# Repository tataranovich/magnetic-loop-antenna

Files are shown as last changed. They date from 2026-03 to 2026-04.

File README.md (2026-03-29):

# Magnetic Loop Antenna

Magnetic loop antenna for receiving HAM radio bands with the following features:

- control over WiFi from web browser
- automatic antenna tune on frequency change in `rtl_tcp` source

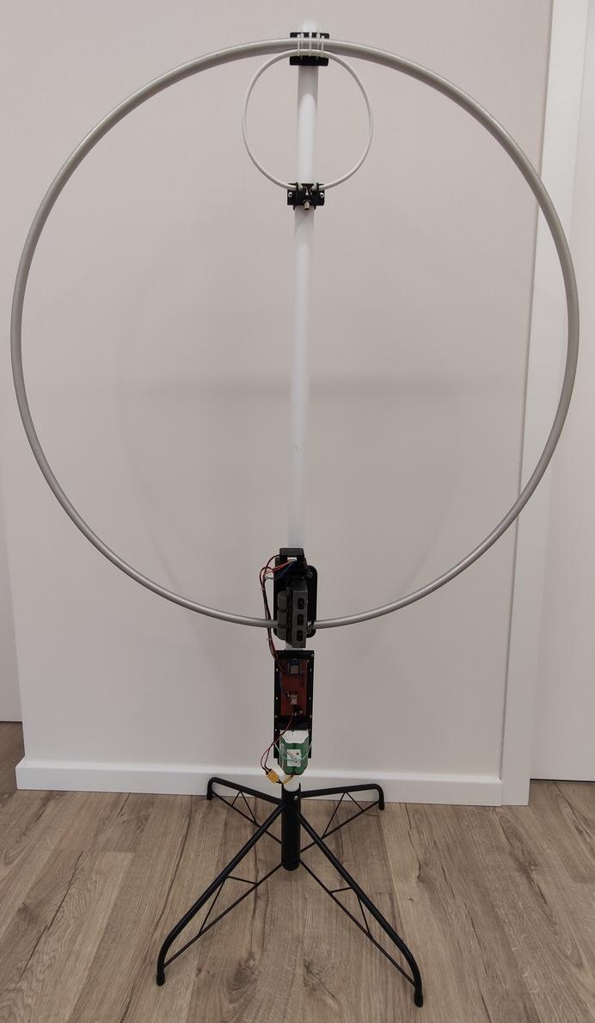
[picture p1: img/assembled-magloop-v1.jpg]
Assembled antenna


Designed using FreeCAD, STL files for printing can be found in `stl` directory.

Assembly details are written in Russian in [blog post](https://blog.tataranovich.com/2026/03/magnetic-loop-antenna.html). Use Google translate if needed.

## Automated Tune

Simple python script to adjust antenna controller settings to match frequency change in `rtl_tcp` backend.

```bash
sudo apt-get update
sudo apt-get install -y rtl-sdr

sudo mkdir /opt/magloop
sudo useradd -r -d /opt/magloop -s /usr/sbin/nologin -G plugdev magloop
sudo install -o root -m 644 magloop-tuner.py /opt/magloop/
sudo install -o root -m 644 magloop-tuner.service /etc/systemd/system/
sudo systemctl daemon-reload
sudo systemctl enable --now magloop-tuner.service
```

## Manual Tune

Antenna can be manually managed from web browser over Wifi or by push buttons at controller board.

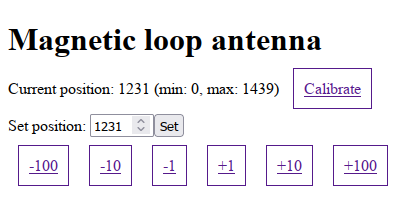
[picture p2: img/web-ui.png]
Web UI


- execute position calibration routine
- set absolute position
- set increase/decrease relative position with different increments

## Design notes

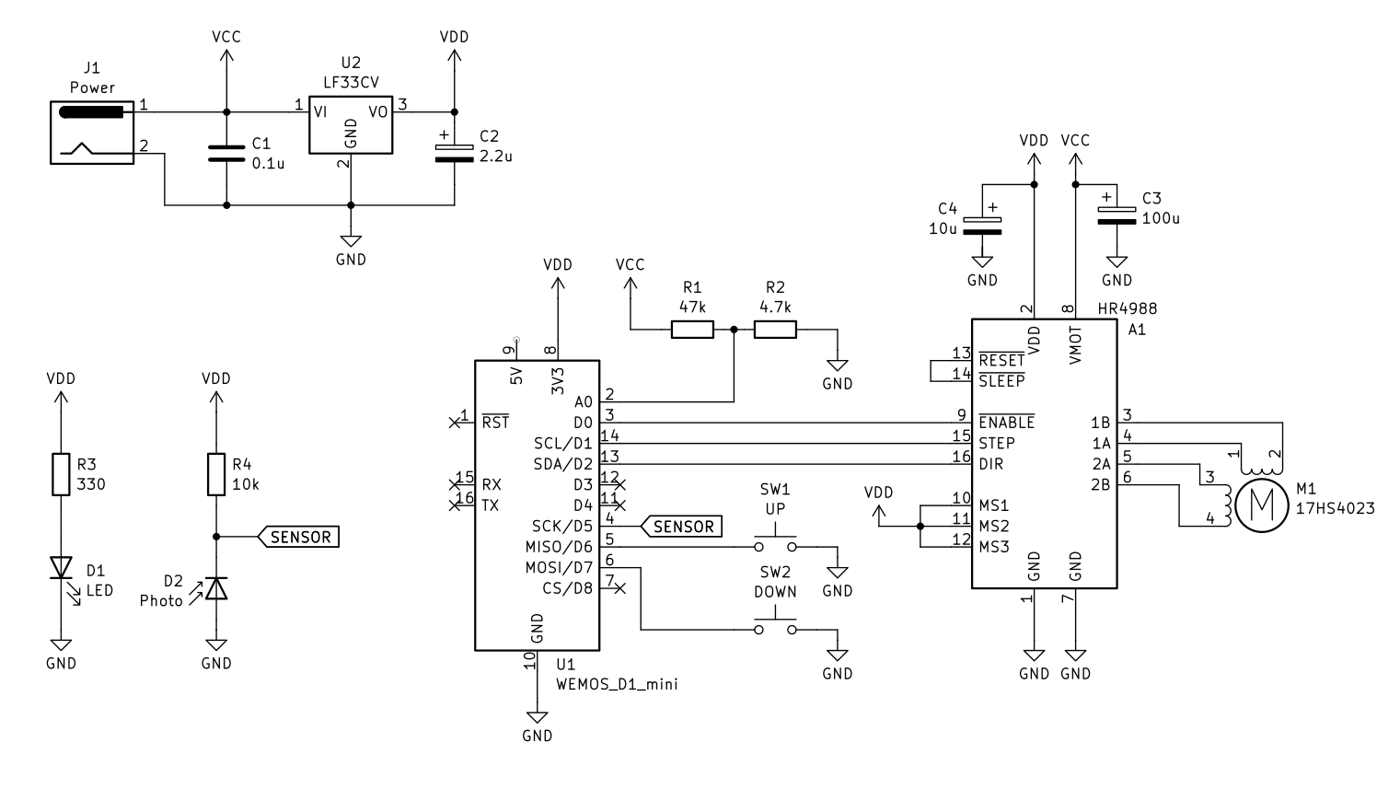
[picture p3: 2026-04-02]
img/magloop-controller-schematic.png

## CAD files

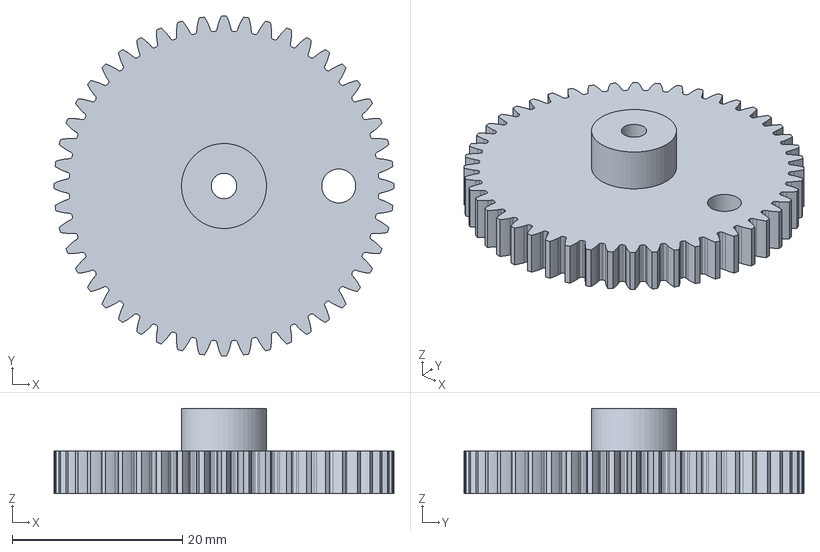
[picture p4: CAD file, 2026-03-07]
freecad/main-geer.FCStd
40.0 x 40.0 x 10.0 mm

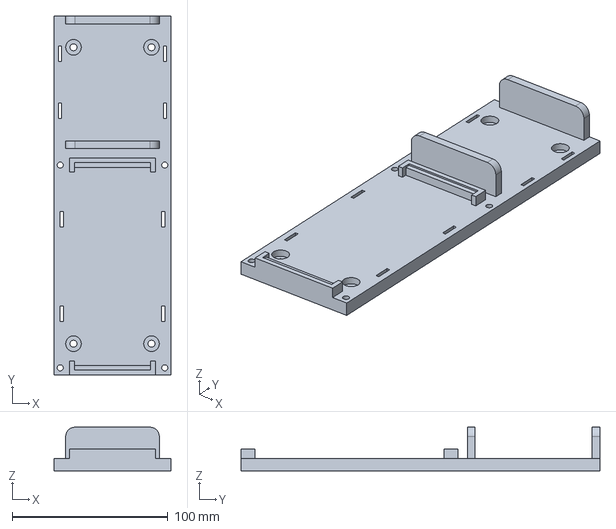
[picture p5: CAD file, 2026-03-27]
freecad/breadboard-stand.FCStd
75.0 x 230.0 x 28.0 mm

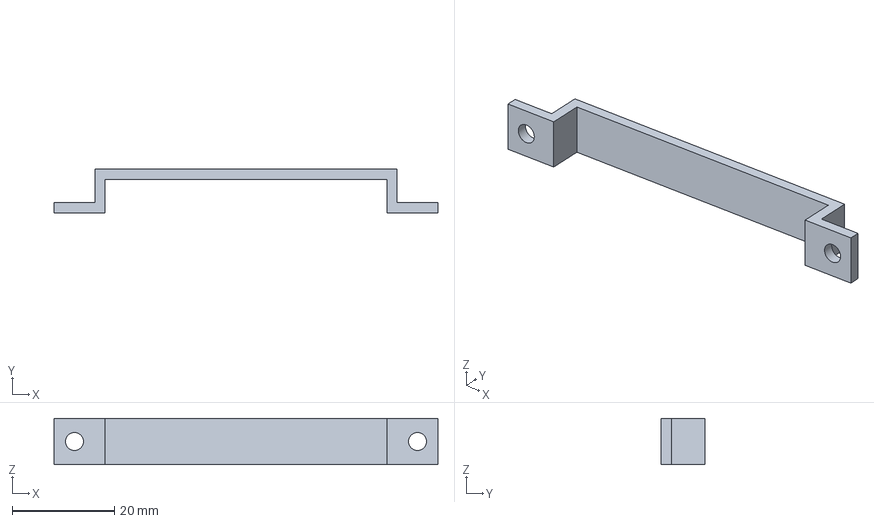
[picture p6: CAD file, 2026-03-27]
freecad/breadboard-skoba.FCStd
75.0 x 8.50 x 9.00 mm

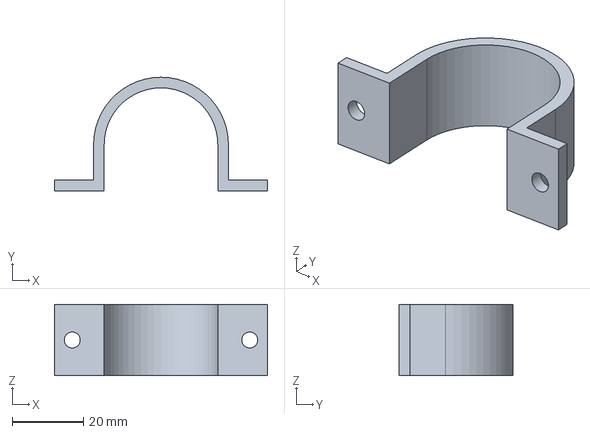
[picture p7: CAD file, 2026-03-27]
freecad/skoba.FCStd
60.0 x 32.0 x 20.0 mm

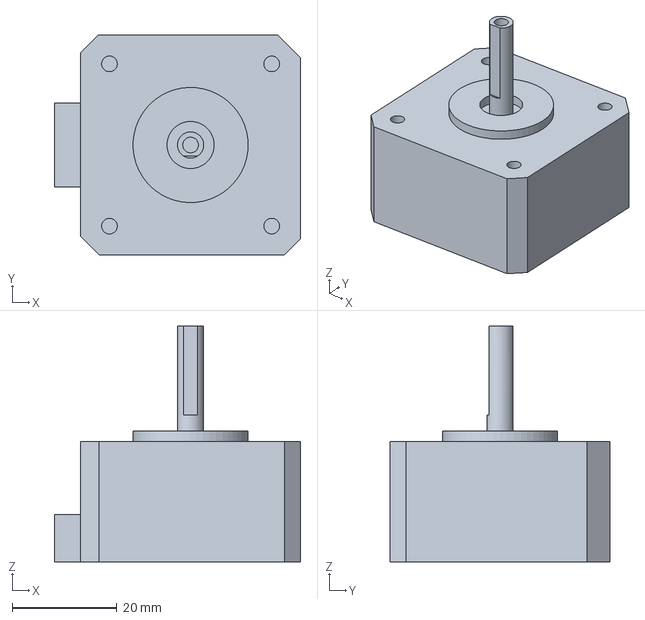
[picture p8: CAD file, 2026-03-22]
freecad/stepper.FCStd
47.0 x 42.0 x 45.0 mm

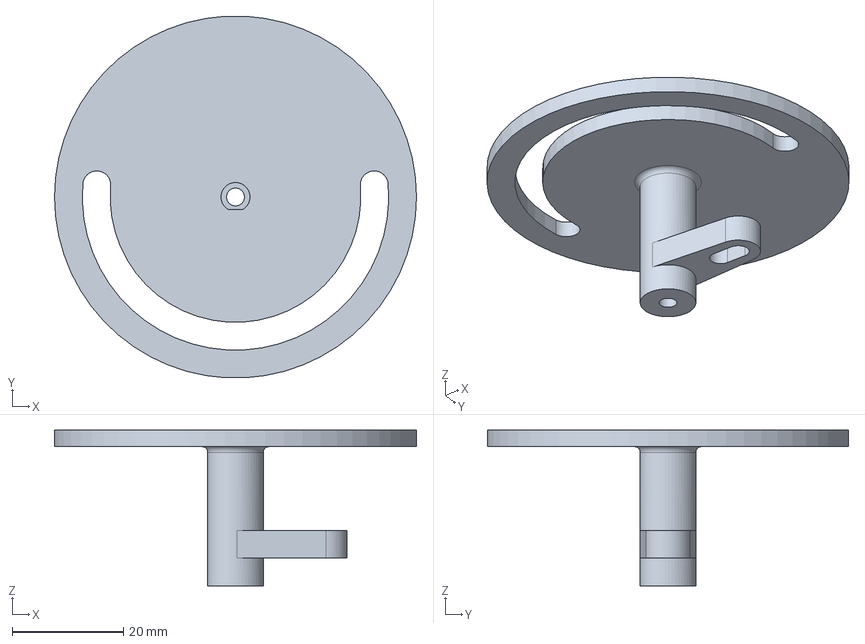
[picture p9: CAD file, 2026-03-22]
freecad/stepper-shaft.FCStd
65.0 x 64.9 x 28.0 mm

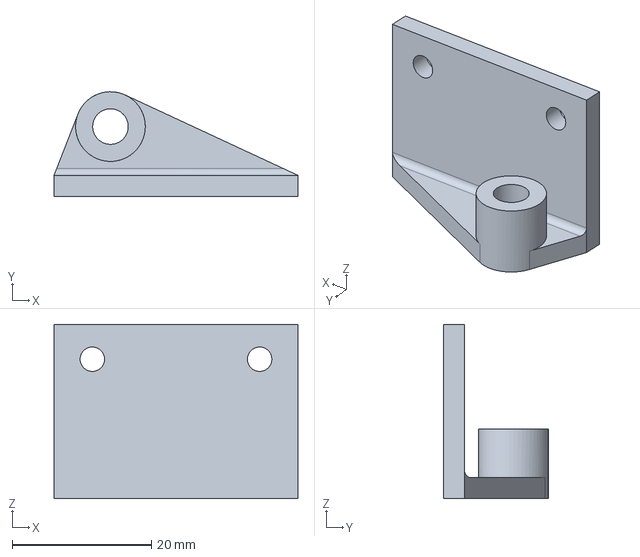
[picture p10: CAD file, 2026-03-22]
freecad/led-stand.FCStd
35.0 x 15.0 x 25.0 mm

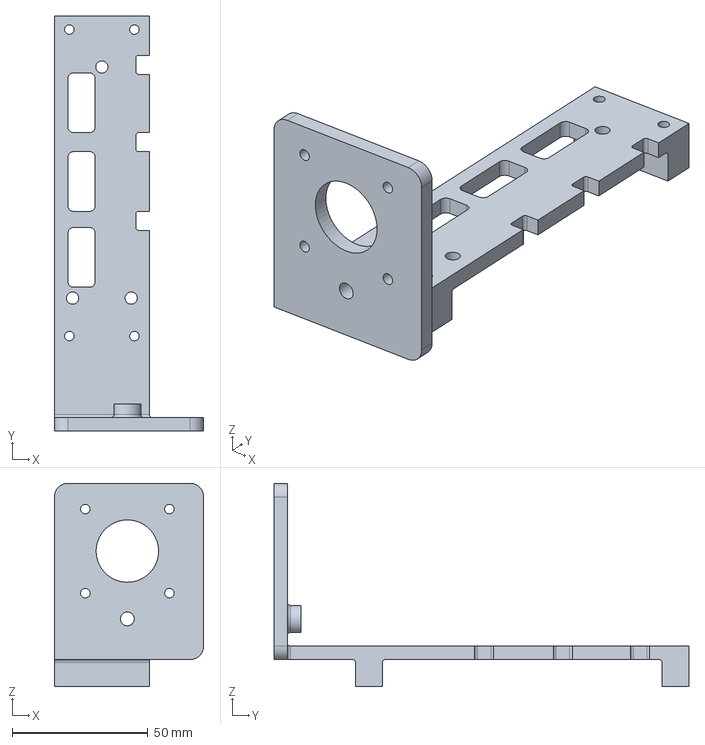
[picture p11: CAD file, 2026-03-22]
freecad/body.FCStd
55.0 x 153.0 x 75.0 mm

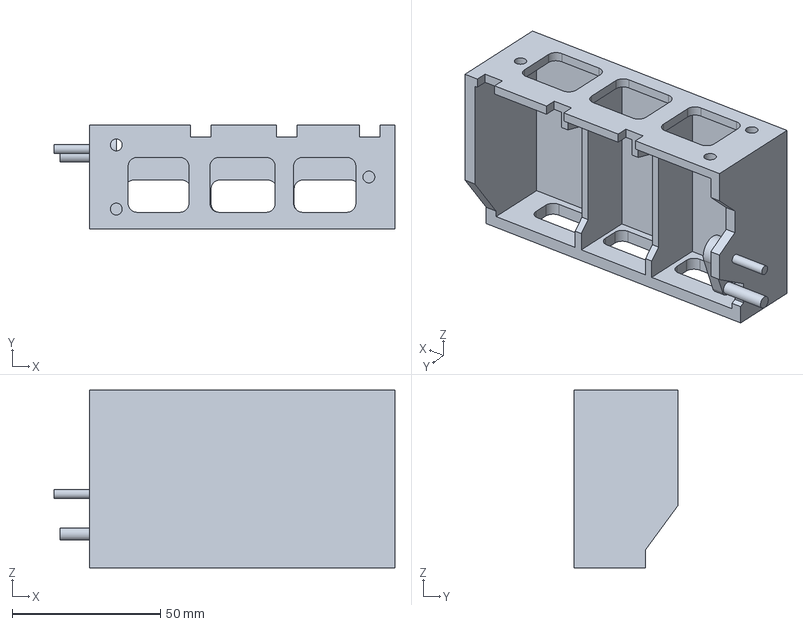
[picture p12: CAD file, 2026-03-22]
freecad/kpe.FCStd
115.0 x 35.0 x 60.0 mm

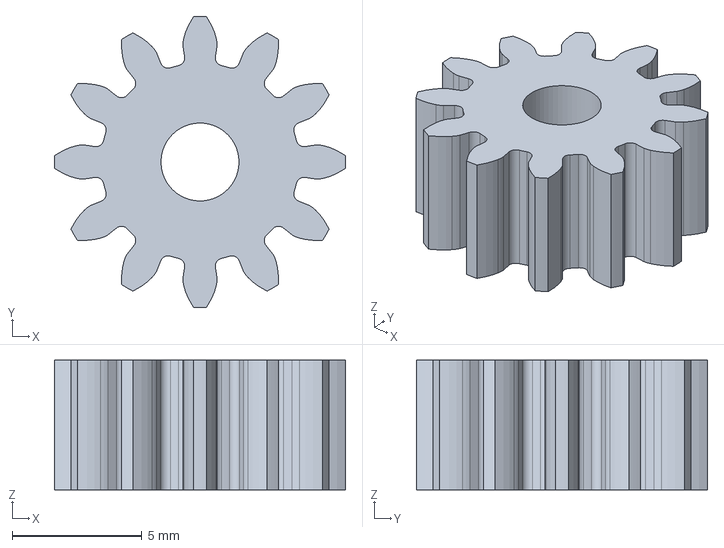
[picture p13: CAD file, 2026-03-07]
freecad/vernier-geer.FCStd
11.2 x 11.2 x 5.00 mm

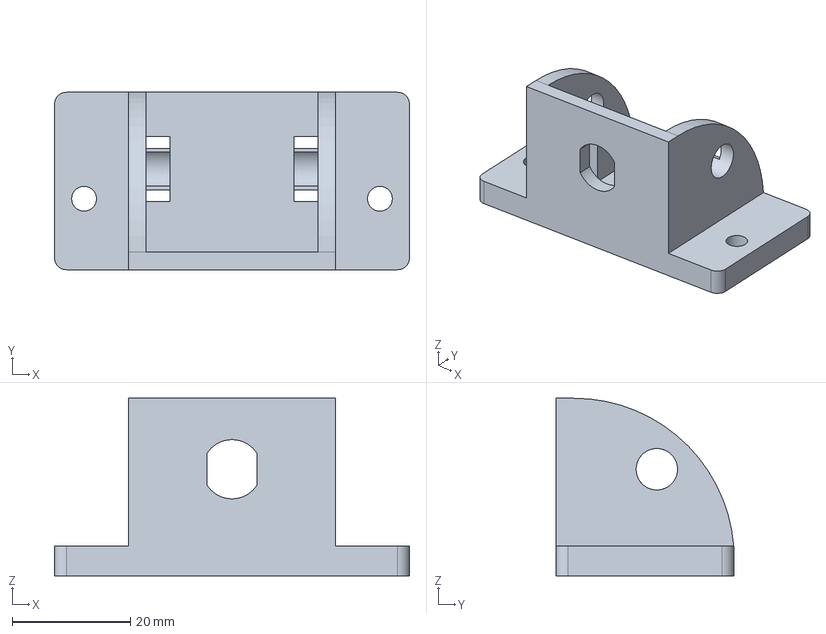
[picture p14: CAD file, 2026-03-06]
freecad/bnc-plate2.FCStd
60.0 x 30.0 x 30.0 mm

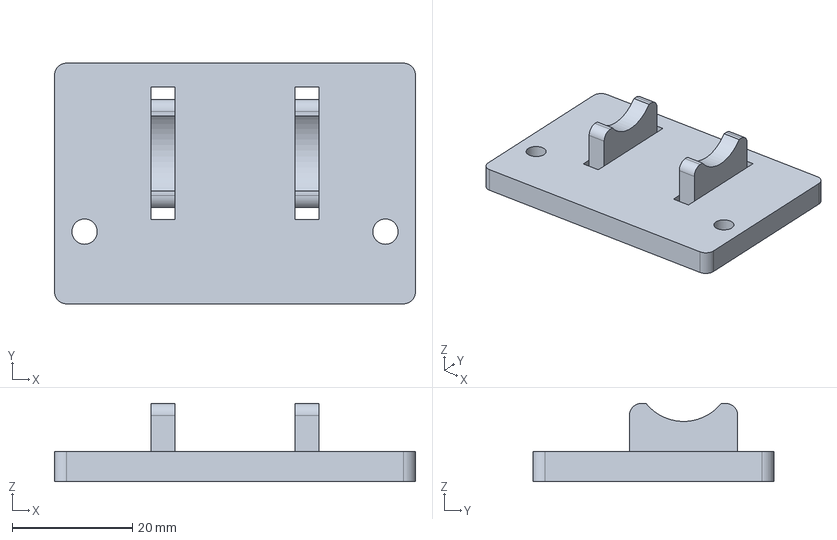
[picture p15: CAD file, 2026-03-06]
freecad/loop-plate.FCStd
60.0 x 40.0 x 13.0 mm

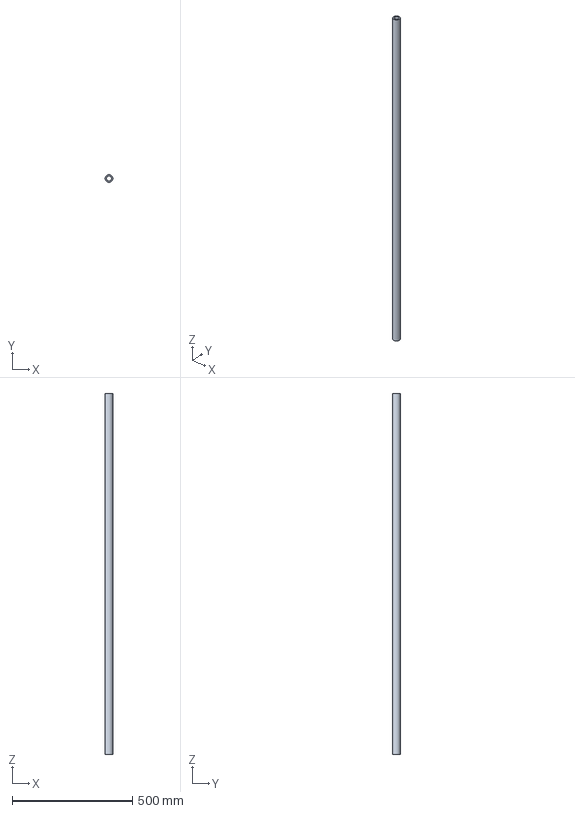
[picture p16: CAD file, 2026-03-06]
freecad/shtanga.FCStd
32.0 x 32.0 x 1500.0 mm

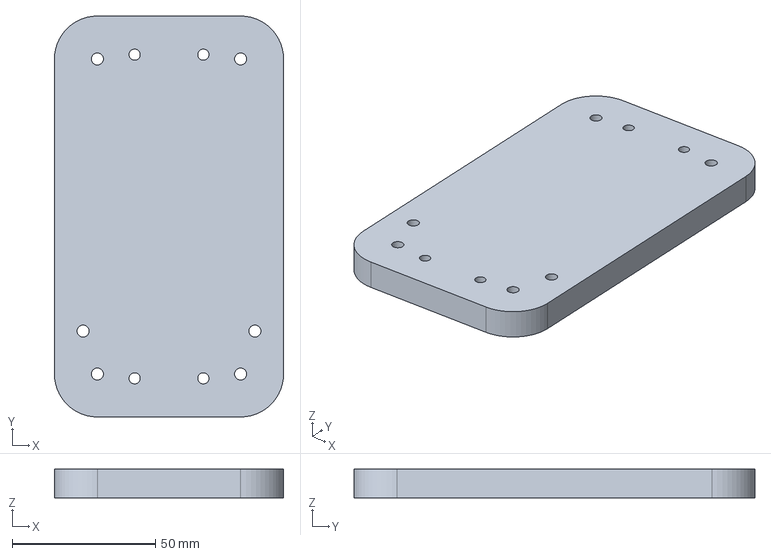
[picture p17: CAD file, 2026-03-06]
freecad/plate.FCStd
80.0 x 140.0 x 10.0 mm

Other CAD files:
freecad/breadboard-assembly.FCStd
freecad/stepper-assembly.FCStd
freecad/Assembly.FCStd
freecad/circle.FCStd
freecad/circle2.FCStd
freecad/end.FCStd
stl/bnc-plate2.stl
stl/body.stl
stl/breadboard-skoba.stl
stl/breadboard-stand.stl
stl/end.stl
stl/led-stand.stl
stl/loop-plate.stl
stl/main-geer.stl
stl/plate.stl
stl/skoba.stl
stl/stepper-shaft.stl

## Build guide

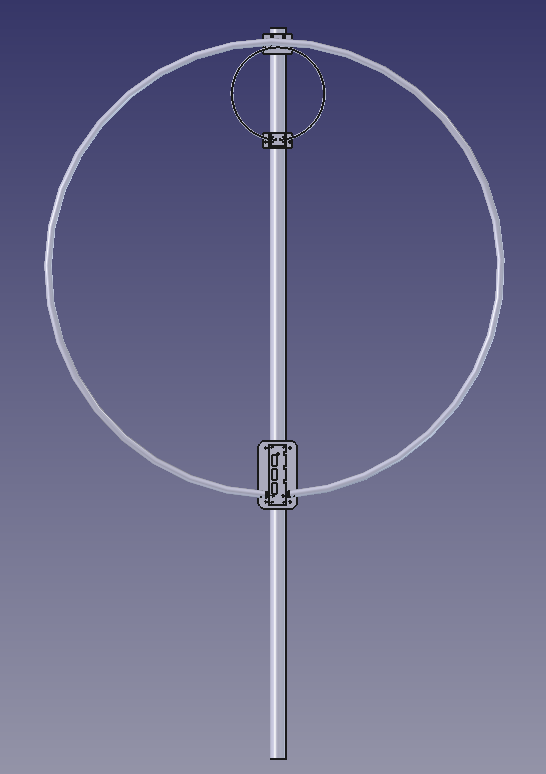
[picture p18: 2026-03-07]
img/magloop-assembly.png

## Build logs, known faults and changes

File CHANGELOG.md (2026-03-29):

# Changelog

All notable changes to this project will be documented in this file.

The format is based on [Keep a Changelog](https://keepachangelog.com/en/1.1.0/),
and this project adheres to [Semantic Versioning](https://semver.org/spec/v2.0.0.html).

## [Unreleased]

### Added

- FreeCAD models for virtual assembly.
- STL files for 3D printing.
- Manual tuning from web browser over WiFi.
- Automatic tuning for `rtl_tcp` backend.

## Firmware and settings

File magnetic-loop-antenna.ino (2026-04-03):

#include "config.h"

#include <ESP8266WiFi.h>
#include <ESP8266WebServer.h>

#define ENABLE_PIN D0
#define STEP_PIN D1
#define DIR_PIN D2
#define SENSOR_PIN D5
#define BTN_UP_PIN D6
#define BTN_DOWN_PIN D7

#define DIR_UP HIGH
#define DIR_DOWN LOW

#define SENSOR_NORMAL LOW
#define SENSOR_ALERT HIGH

#define POSITION_MARGIN 150

#define VOLTAGE_MAX 35.0 // 47k + 4.7k resistor divider
#define VOLTAGE_MIN 12.0 // Stop WiFi and go to infitinite sleep if voltage is below

int position = 0;
int minPosition;
int maxPosition;

bool stepperEnabled;
bool stepperAutoDisable;
uint32_t stepperLastUse;

String webString;
ESP8266WebServer server(80);

void wifi_action_index() {
  String response = "<!doctype html><html lang=\"en\">"
  "<head><meta charset=\"utf-8\" /><title>Magnetic Loop Antenna</title>"
  "<style>.button {margin: 10px; padding: 10px; border: 1px solid}</style></head>"
  "<body><h1>Magnetic loop antenna</h1>"
  "<p>Current position: " + String(position) + " (min: " + String(minPosition) + ", max: " + String(maxPosition) + ") <a class=\"button\" href=\"/calibrate\">Calibrate</a></p>"
  "<form action=\"/setPosition\" method=\"GET\">"
  "Set position: <input type=\"number\" name=\"abs\" min=\"" + String(minPosition) + "\" max=\"" + String(maxPosition) + "\" value=\"" + String(position) + "\">"
  "<input type=\"submit\" name=\"set\" value=\"Set\">"
  "</form><br/>"
  "<a class=\"button\" href=\"/stepDown?step=100\">-100</a>"
  "<a class=\"button\" href=\"/stepDown?step=10\">-10</a>"
  "<a class=\"button\" href=\"/stepDown?step=1\">-1</a>"
  "<a class=\"button\" href=\"/stepUp?step=1\">+1</a>"
  "<a class=\"button\" href=\"/stepUp?step=10\">+10</a>"
  "<a class=\"button\" href=\"/stepUp?step=100\">+100</a>"
  "<p>Voltage: " + String(getVoltage()) + " V</p>"
  "</body></html>";
  server.send(200, "text/html", response);
}

void wifi_action_setPosition() {
  int setPosition;
  if (server.hasArg("abs")) {
    setPosition = server.arg("abs").toInt();
    if (setPosition > position) {
      while (position < setPosition) {
        stepUp(1);
      }
    } else if (setPosition < position) {
      while (position > setPosition) {
        stepDown(1);
      }
    }
  }
  wifi_action_index();
}

void wifi_action_stepUp() {
  int stepValue = 1;
  if (server.hasArg("step")) {
    stepValue = server.arg("step").toInt();
  }
  for (int i = 0; i < stepValue; i++) {
    stepUp(1);
  }
  wifi_action_index();
}

void wifi_action_stepDown() {
  int stepValue = 1;
  if (server.hasArg("step")) {
    stepValue = server.arg("step").toInt();
  }
  for (int i = 0; i < stepValue; i++) {
    stepDown(1);
  }
  wifi_action_index();
}

void wifi_action_calibrate() {
  doCalibration();
  wifi_action_index();
}

void initWifi() {
  WiFi.mode(WIFI_STA);
  WiFi.begin(wifi_ssid, wifi_password);

  Serial.println("Connecting to WiFi network");

  while (WiFi.status() != WL_CONNECTED) {
    delay(500);
    Serial.print(".");
  }
  Serial.println("");
  Serial.println("WiFi connected");

  server.begin();
  server.on("/", wifi_action_index);
  server.on("/stepUp", wifi_action_stepUp);
  server.on("/stepDown", wifi_action_stepDown);
  server.on("/setPosition", wifi_action_setPosition);
  server.on("/calibrate", wifi_action_calibrate);
  Serial.println("Server started");

  Serial.println(WiFi.localIP());
}

void doWifi() {
  server.handleClient();
}

bool isSensorAlert() {
  return digitalRead(SENSOR_PIN) == SENSOR_ALERT;
}

float getVoltage() {
  return analogRead(A0)*(VOLTAGE_MAX/1023);
}

void doCalibration() {
  minPosition = 0;
  maxPosition = 1600; // Max steps for 180 degrees

  Serial.println("Calibrating...");

  // Handle unknown MIN or MAX position when sensor is alerting
  // Try to tune up a bit if we below minimal position
  if (isSensorAlert()) {
    Serial.println("Sensor is HIGH, checking if below MIN position");
    position = minPosition;
    for (int i = 0; i < POSITION_MARGIN; i++) {
      stepUp(10);
      if (!isSensorAlert()) {
        position = minPosition;
        break;
      }
    }
  }

  // If sensor still alerting then we above maximum position
  if (isSensorAlert()) {
    Serial.println("Sensor is HIGH, checking if above MAX position");
    position = maxPosition;
    for (int i = 0; i < POSITION_MARGIN; i++) {
      stepDown(10);
      if (!isSensorAlert()) {
        position = maxPosition;
        break;
      }
    }
  }

  if (!isSensorAlert()) {
    Serial.println("Sensor is NORMAL, searching safe MIN and MAX positions");
    while (!isSensorAlert()) {
      stepDown(1);
    }
    position = 0;

    // Rewind a bit back before looking MAX position
    for (int i = 0; i < POSITION_MARGIN; i++)
      stepUp(1);

    while (!isSensorAlert()) {
      stepUp(1);
    }
    maxPosition = position;

    for (int i = 0; i < maxPosition; i++) {
      stepDown(1);
    }

    getInfo();
  } else {
    Serial.println("Sensor still ALERT, unable to calibrate");
  }
}

void doStep(int delay_ms) {
  enableStepper();
  digitalWrite(STEP_PIN, HIGH);
  delay(delay_ms);
  digitalWrite(STEP_PIN, LOW);
  delay(delay_ms);
}

void stepUp(int delay_ms) {
  digitalWrite(DIR_PIN, DIR_UP);
  doStep(delay_ms);
  position++;
}

void stepDown(int delay_ms) {
  digitalWrite(DIR_PIN, DIR_DOWN);
  doStep(delay_ms);
  position--;
}

void enableStepper() {
  digitalWrite(ENABLE_PIN, LOW);
  stepperLastUse = millis();
  stepperEnabled = true;
}

void disableStepper() {
  digitalWrite(ENABLE_PIN, HIGH);
  stepperEnabled = false;
}

void getInfo() {
  Serial.println("\n\nCurrent position: " + String(position) + " (min: " + String(minPosition) + ", max: " + String(maxPosition) + ")");
  Serial.println("Voltage: " + String(getVoltage()) + " V");

  Serial.print("Sensor is ");
  if (isSensorAlert()) {
    Serial.println("ALERT");
  } else {
    Serial.println("NORMAL");
  }

  Serial.print("Stepper is ");
  if (stepperEnabled) {
    Serial.println("ENABLED");
  } else {
    Serial.println("DISABLED");
  }
}

void initSerial() {
  Serial.begin(115200);
}

void doSerial() {
    if (Serial.available() > 0) {
    String input = Serial.readStringUntil('\n');
    input.trim();

    if (input.length() > 0) {
      char command = input.charAt(0);
      int spaceIndex = input.indexOf(' ');
      int command_value = 1;
      if (spaceIndex > 0) {
        command_value = input.substring(spaceIndex + 1).toInt();
      }
      if (command == 'c') {
        doCalibration();
      } else if (command == 'u') {
        for (int i = 0; i < command_value; i++)
          stepUp(10);
      } else if (command == 'd') {
        for (int i = 0; i < command_value; i++)
          stepDown(10);
      } else if (command == 'U') {
        for (int i = 0; i < command_value; i++)
          stepUp(1);
      } else if (command == 'D') {
        for (int i = 0; i < command_value; i++)
          stepDown(1);
      } else if (command == 'i') {
        getInfo();
      }
    }
  }
}

void initButtons() {
  pinMode(BTN_DOWN_PIN, INPUT_PULLUP);
  pinMode(BTN_UP_PIN, INPUT_PULLUP);
}

void doButtons() {
  // Button UP is pressed
  if (digitalRead(BTN_UP_PIN) == LOW && digitalRead(BTN_DOWN_PIN) == HIGH) {
    stepUp(10);
  }

  // Button DOWN is pressed
  if (digitalRead(BTN_DOWN_PIN) == LOW && digitalRead(BTN_UP_PIN) == HIGH) {
    stepDown(10);
  }
}

void initStepper() {
  pinMode(ENABLE_PIN, OUTPUT);
  pinMode(STEP_PIN, OUTPUT);
  pinMode(DIR_PIN, OUTPUT);
  pinMode(SENSOR_PIN, INPUT);

  enableStepper();
  stepperAutoDisable = true;
}

void doStepper() {
  // Disable stepper driver after 1 second of inactivity
  if (stepperAutoDisable && stepperEnabled) {
    if (millis() > stepperLastUse + 1000) {
      disableStepper();
    }
  }
}

void doLowVoltage() {
  if (getVoltage() <= 12.0) {
    Serial.println("Voltage is LOW");
    WiFi.mode(WIFI_STA);
    WiFi.disconnect();
    WiFi.mode(WIFI_OFF);
    disableStepper();
    ESP.deepSleep(0);
  } else {
    Serial.println("Voltage is NORMAL");
  }
}

void setup() {
  initSerial();
  Serial.println("\n\n\nMagnetic Loop Antenna\n\n\n");

  initStepper();
  initButtons();

  doLowVoltage();

  doCalibration();

  initWifi();
}

void loop() {
  doSerial();
  doButtons();
  doStepper();
  doWifi();
  doLowVoltage();
}

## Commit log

2026-03-01 KPE stand, plate, skoba
    [Assembly.FCStd, body.FCStd, circle.FCStd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]
2026-03-06 BNC plate, end, circle2
    [Assembly.FCStd, bnc-plate.FCStd, body.FCStd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]
2026-03-06 Refactor BNC and loop plates
    [Assembly.FCStd, bnc-plate.FCStd, bnc-plate2.FCStd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]
2026-03-22 Stepper motor
    [Assembly.FCStd, bnc-plate2.FCStd, body.FCStd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]
2026-03-22 Basic Arduino sketch to control stepper
2026-03-27 Disable stepper sooner
    [skoba.FCStd, skoba.stl]
2026-03-27 Breadboard stand
    [breadboard-assembly.FCStd, breadboard-skoba.FCStd, breadboard-skoba.stl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]
2026-03-28 On demand calibration
2026-03-29 Magnetic loop tuner
2026-04-01 Print supply voltage
2026-04-02 Kicad files
    [magloop-controller.kicad_pcb, magloop-controller.kicad_sch]
2026-04-03 Protect battery from overdischarge
